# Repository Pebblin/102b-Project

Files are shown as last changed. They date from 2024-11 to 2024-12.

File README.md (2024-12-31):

# 102b-Project

## Folders
                
+ Submission
    + Project Report
    + Final Video
+ Project Code
    + Testing .ino file
    + Main code folder (contains pattern functionality)
    + Submitted code folder (meets criteria of assignment)
+ Printing Files
    + Contains different versions of printed parts used in the table
+ P4 Design
    + Contains .stl files of parts used to make the assembly CAD
+ CAD/CAD Scaled Down Model
    + Main Assembly and other .part files necessary for the assembly
    + Rudementary design of a previous project idea

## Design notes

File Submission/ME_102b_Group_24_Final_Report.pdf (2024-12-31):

# ME 102B: Kinetic Sand Table

Group 24

Rocklin Duong, Nilesh Kothari, Taylor Jazan, Rahul Kariyawasam

19th December 2024

## 1. Device Discussion

### 1.1 Opportunity

This project explores the creation of a motor-powered sand table, an engaging device that combines automation and user interaction for creating intricate patterns in sand. The opportunity lies in blending art and technology to develop a device that is functional, creative, and accessible. The sand table can serve as a captivating display piece, a creative tool, or an interactive installation, merging the worlds of technology and art in an innovative way.

### 1.2 High-Level Strategy

The sand table uses a dual-axis motorized system to move a steel ball over the sand’s surface, guided by a magnet underneath. The control system includes an ESP32 microcontroller, two motors, a motor driver, a joystick, and limit switches. This design enables two operational modes: automated and manual.
From our initial desired functionality, we were able to accomplish nearly everything that we wanted. Though we were unable to implement online functionality, we did instead allow for manual control in both cardinal and diagonal directions.

### 1.3 Design

The design of the motor-powered sand table consists of a dual-axis system using linear rails and a timing belt mechanism. The motorized system allows for precise movement of a steel ball over a sand surface to create intricate patterns. Full size photos can be found in the appendix.

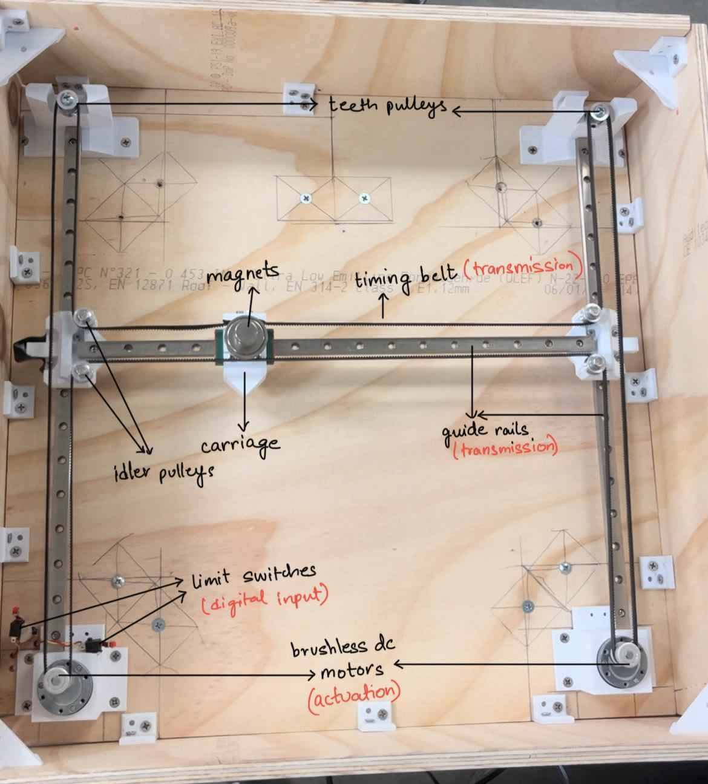
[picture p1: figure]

Figure 1: Photo of table with labels

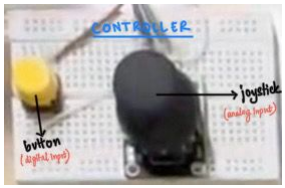
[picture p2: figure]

Figure 2: Photo of controller with labels

## 2. Calculations

In this section, we derive the key performance requirements and mechanical parameters for the linear rail and timing belt assembly used in the project. The system employs two brushed DC motors (for two degrees of freedom), a timing belt mechanism for translation, and ball bearings for load support. For simplicity and consideration of “worst case scenario,” calculations are assumed for only one motor driving the assembly.
Note that these calculations do not take into account friction between the carriage(s) and the linear rails, or the friction due to the tension of the timing belt. However, these values are assumed to be negligible due to the use of quality ball bearings in the linear rail assembly, and a relatively low belt tension, respectively.

### 2.1 Required Torque for Each Motor

The required torque for each DC motor is determined based on the motor’s maximum speed, the pulley radius, and the carriage acceleration. The system uses a pulley with radius r = 6.5 mm = 0.0065 m and a motor shaft speed of 250 rpm (revolutions per minute). The linear velocity vmax of the carriage is given by:
vmax = ω · r,

where ω is the angular velocity of the motor shaft in radians per second. Converting 250 rpm to radians per second and plugging in:

vmax = 250 ×

2π
60
- 0.0065 = 0.170 m/s.

Assuming a rapid start-stop scenario (constant acceleration), the maximum acceleration amax is estimated using kinematics:

amax =

v

2
max
2L

,

where L is the stopping distance. For simplicity, assume a realistic stopping distance L = 0.01 m. Substituting values:

amax =

(0.170)²
2 · 0.01

= 1.445 m/s²

The torque T required at the motor shaft to achieve this acceleration is given by:

T = F · r, F = m · amax

where F is the force required to accelerate the carriage. Given an assembly mass of m = 0.071 kg, the required torque is:
T = F · r = 0.071 · 1.445 · 0.0065 = 6.67 × 10⁻³ Nm (6.67 mNm).

This torque is well within the operating limits of the DC motors used, which have a maximum stall torque of 18 kg·cm, or 1.76 Nm.

### 2.2 Required Timing Belt Tension

To determine the required tension Tbelt in the timing belt, we consider the force needed to overcome inertia during acceleration and account for belt elasticity. The tension in the belt can be approximated as:

Tbelt = Fload + Fdynamic,

where Fload is the force due to carriage assembly weight, and Fdynamic is the force due to acceleration:

Fload = m · g = 0.071 · 9.81 = 0.696 N, Fdynamic = m · amax = 0.071 · 1.445 = 1.026 N.

The total belt tension required is approximately:

Tbelt = Fload + Fdynamic = 0.696 + 1.026 ≈ 1.722 N.

### 2.3 Maximum Radial Loads on Ball Bearings and Motor Shaft

The system’s ball bearings and motor shafts experience radial forces during operation due to belt tension and carriage movement. The maximum radial load on each ball bearing is approximately equal to the belt tension, as the force from the belt tension is transferred directly to the bearings.

Fbearing = Tbelt = 1.722 N.

The radial load on the motor shaft arises from the belt tension and the pulley geometry. The radial force Fshaft can be estimated using the belt tension and the belt angle of entry θ to the pulley. Assuming θ = 0◦
from our design (also a maximum load scenario):

Fshaft = Tbelt · cos(θ), Fshaft = Tbelt = 1.722 N.

The calculated loads are within the acceptable operating limits of our ball bearings and motor shafts, as the ball bearings of our system are rated for a maximum load of 200 N.

## 3. Diagrams

Full-scale photos of the below diagrams can also be found in the appendix.

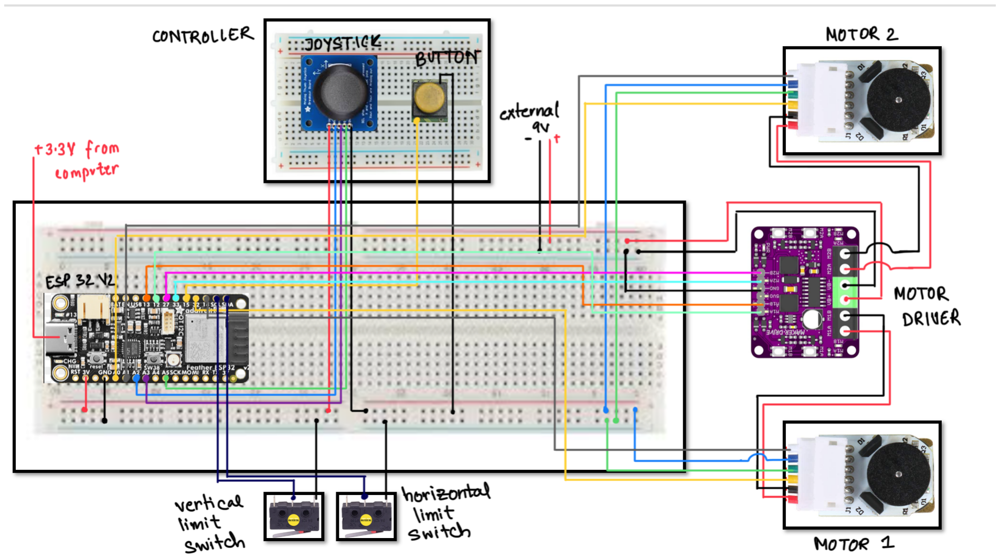
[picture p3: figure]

Figure 3: Circuit Diagram

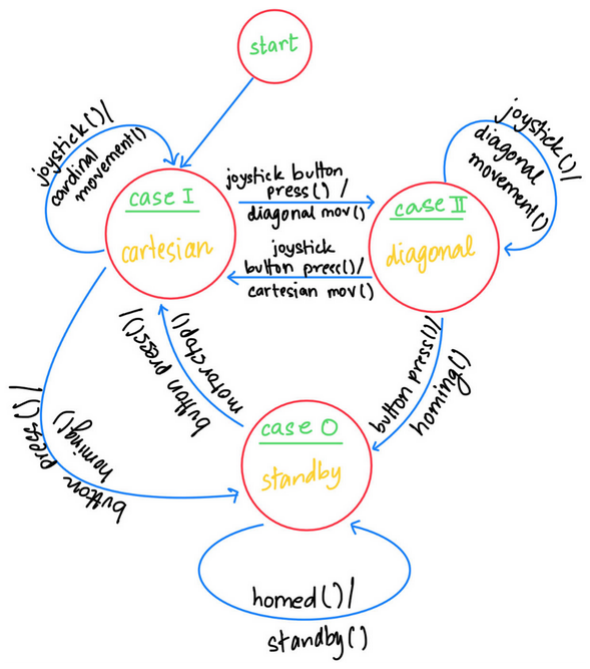
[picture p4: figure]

Figure 4: State Transition Diagram

## 4. Reflection

One strategy that worked well for our group was clear communication and task delegation. By setting realistic deadlines and holding regular check-ins, we maintained steady progress and avoided last-minute stress. However, we wish we had prototyped earlier in the process. Testing a mid-fidelity version of our design sooner would have helped us identify issues like motor strength and alignment earlier, saving time during the final build. Overall, balancing planning with hands-on testing is key to a smooth and successful project.

## 5. Appendix

### 5.1 Appendix A: Bill of Materials

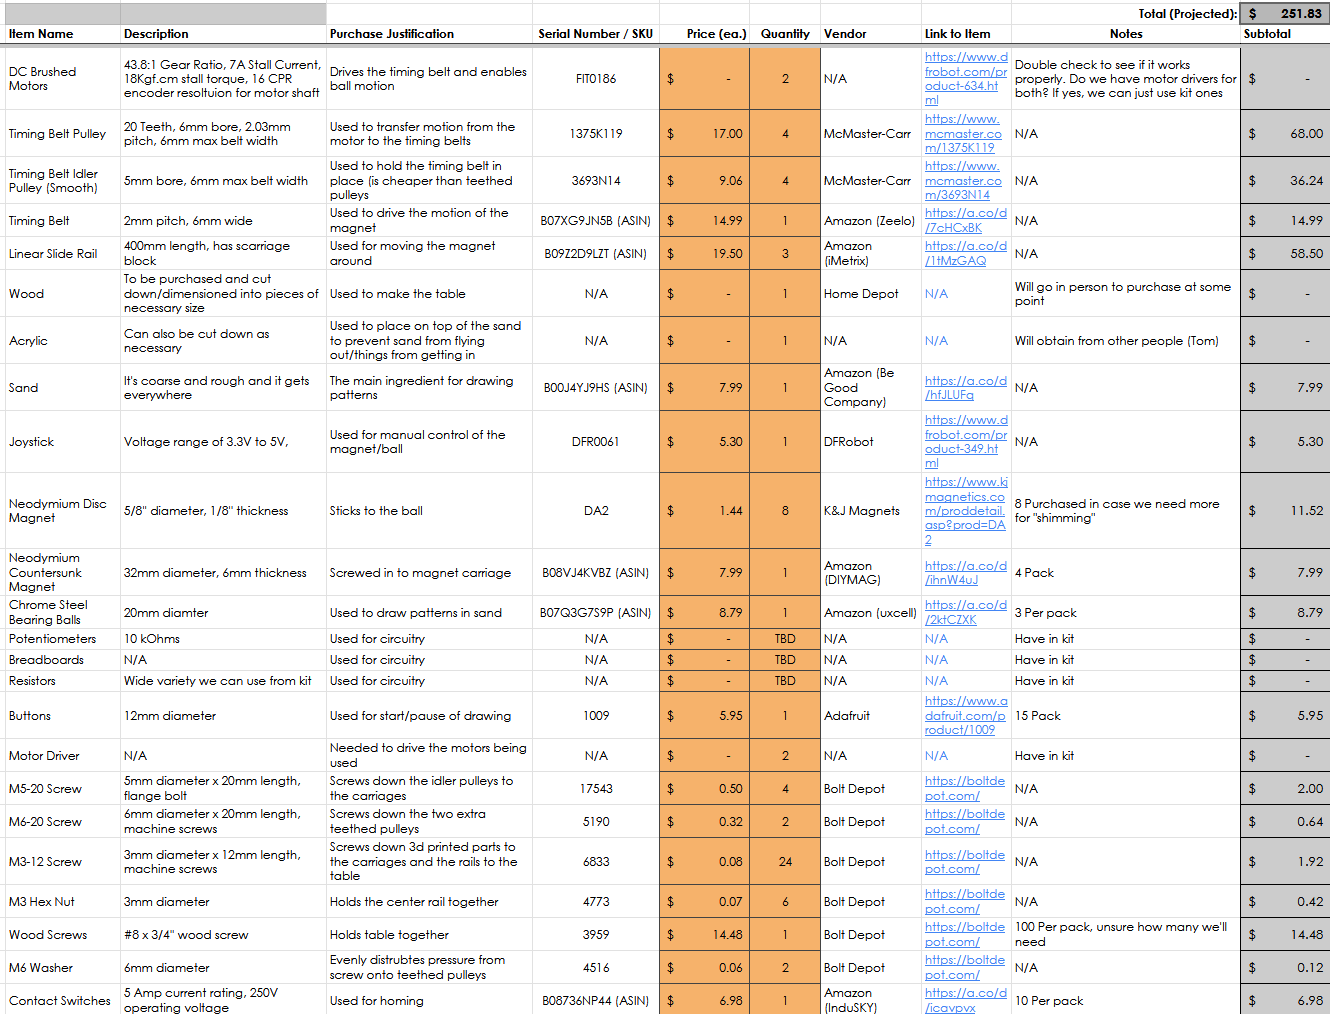
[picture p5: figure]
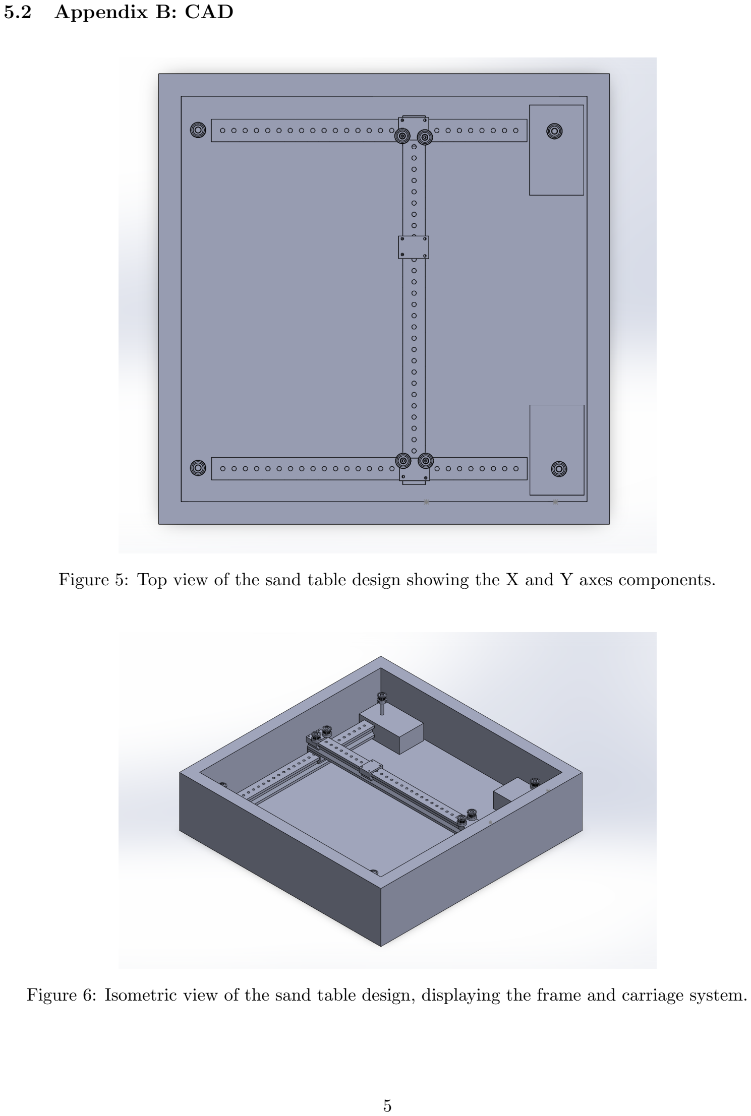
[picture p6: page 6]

### 5.2 Appendix B: CAD

Figure 5: Top view of the sand table design showing the X and Y axes components.

Figure 6: Isometric view of the sand table design, displaying the frame and carriage system.

### 5.3 Appendix C: Code Screenshots

The order of the screenshots go in order of Main.ino, then MotorControl, JoystickHandler, and EncoderHandler. For the last three classes, the .hpp file is shown then the .cpp file.

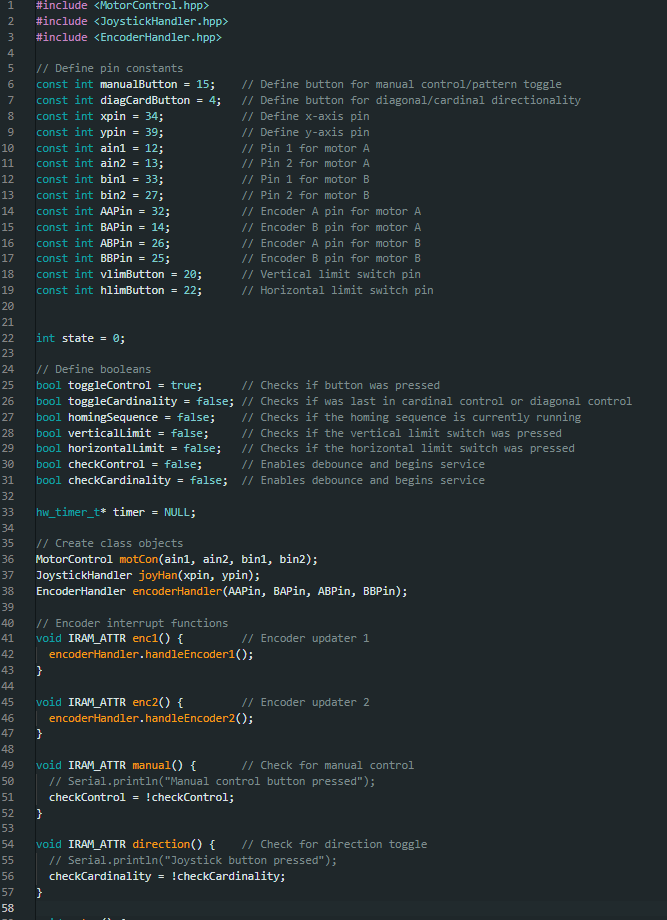
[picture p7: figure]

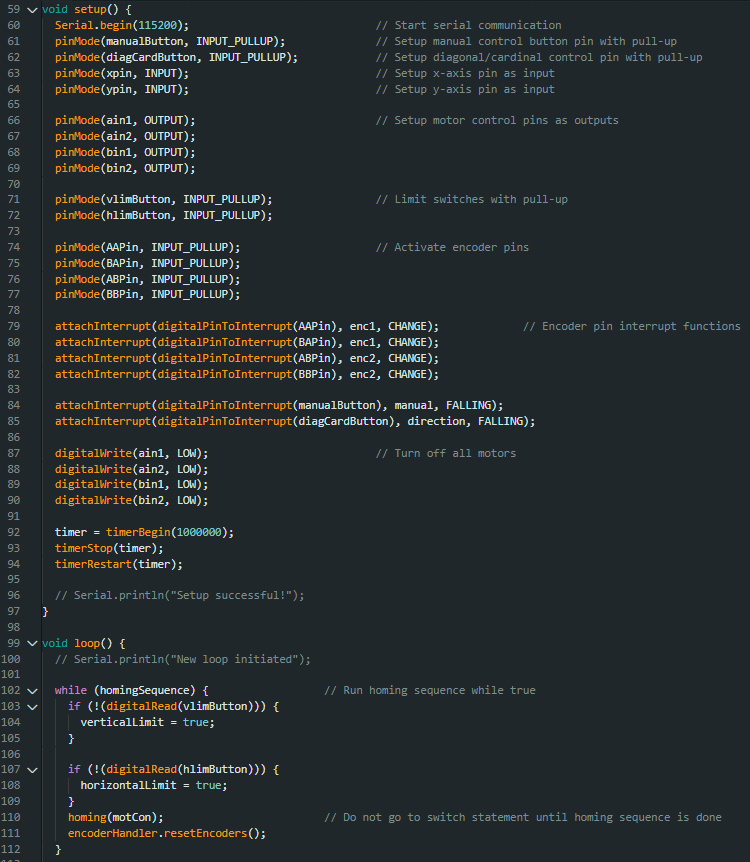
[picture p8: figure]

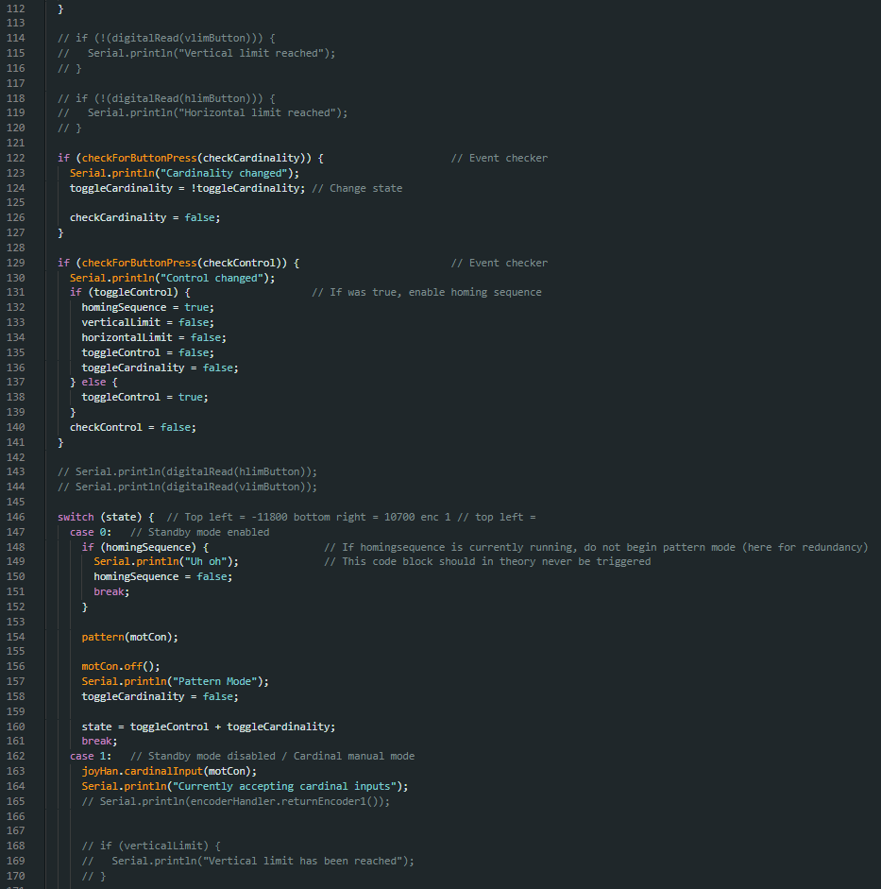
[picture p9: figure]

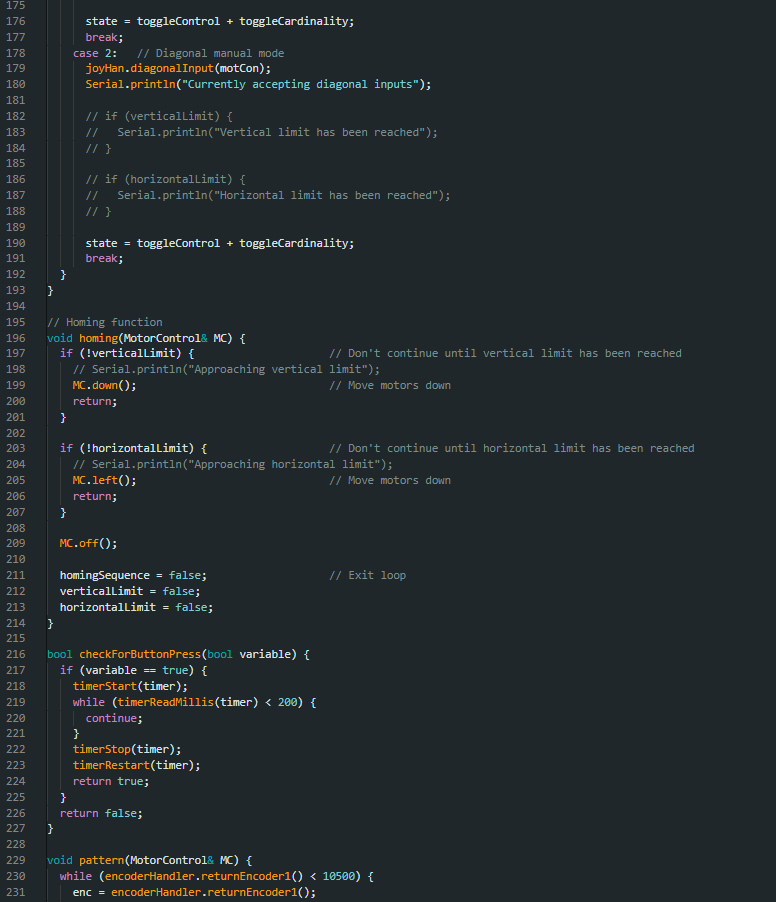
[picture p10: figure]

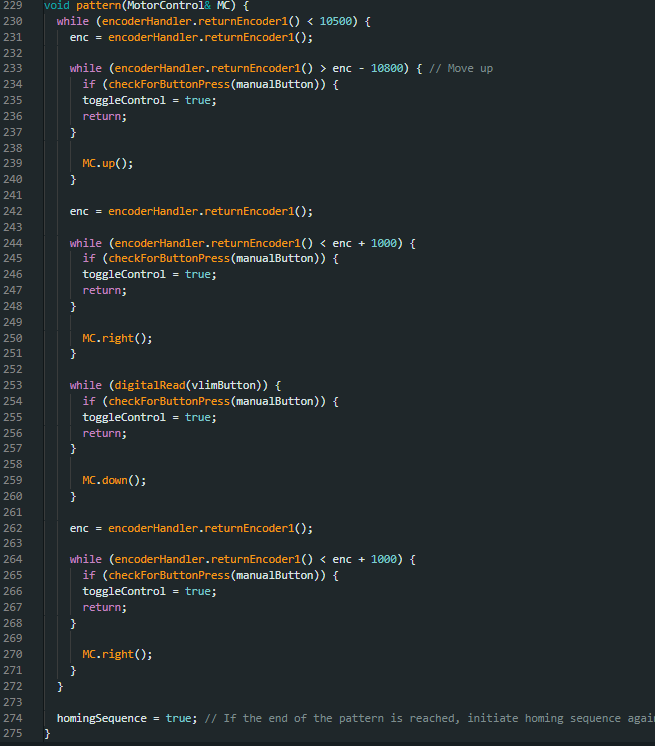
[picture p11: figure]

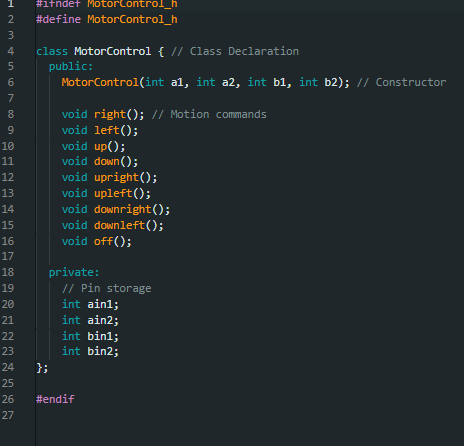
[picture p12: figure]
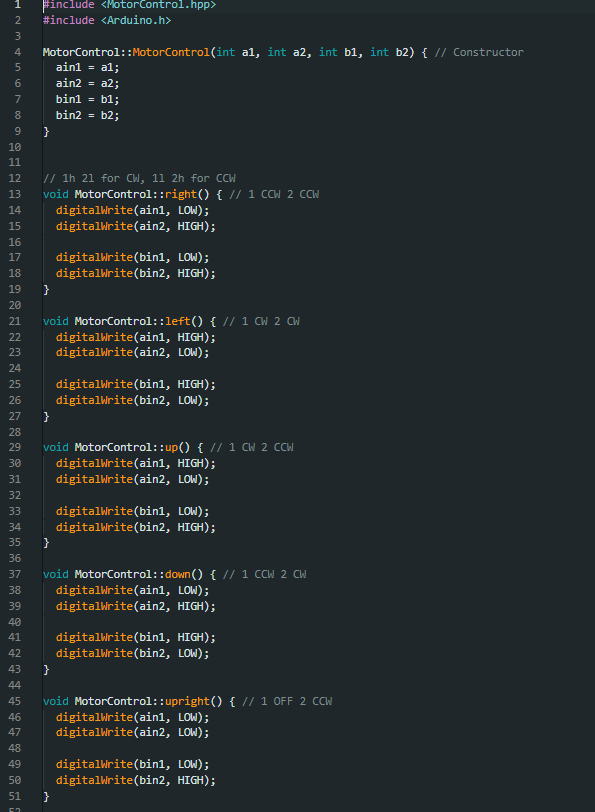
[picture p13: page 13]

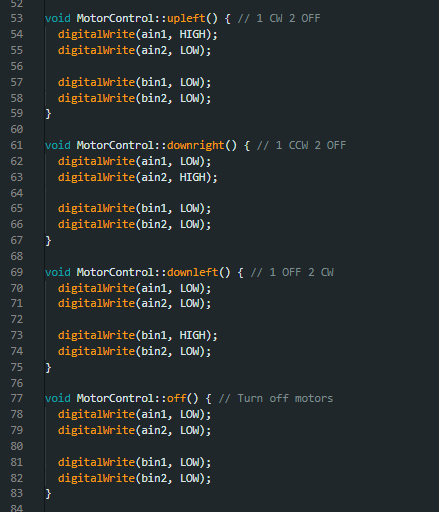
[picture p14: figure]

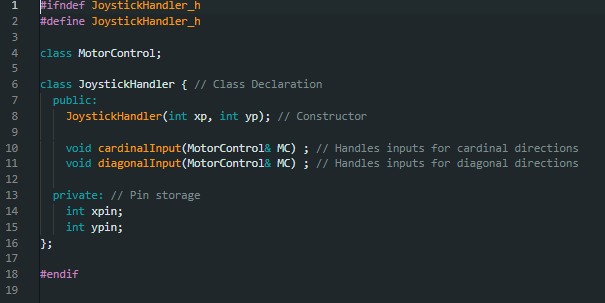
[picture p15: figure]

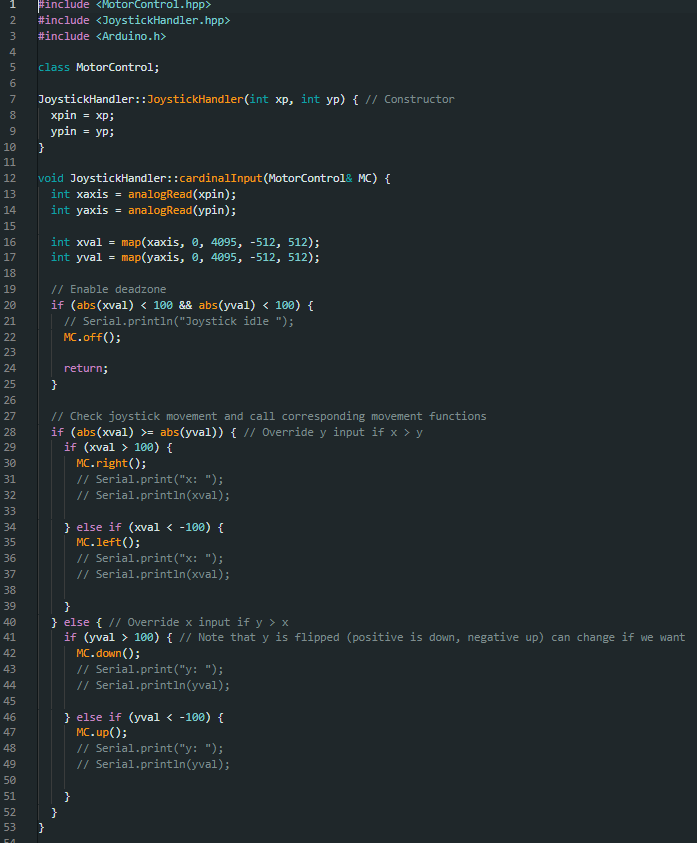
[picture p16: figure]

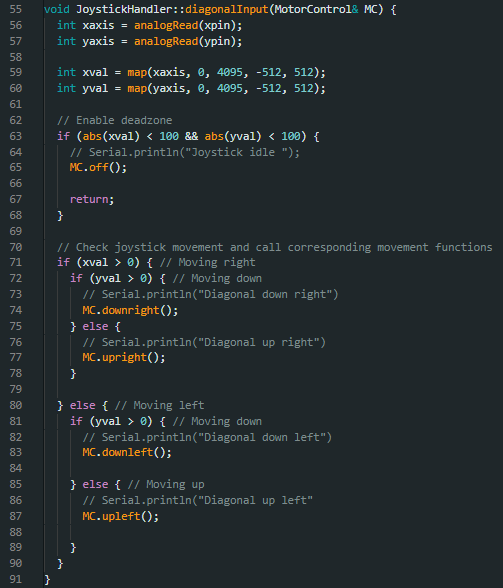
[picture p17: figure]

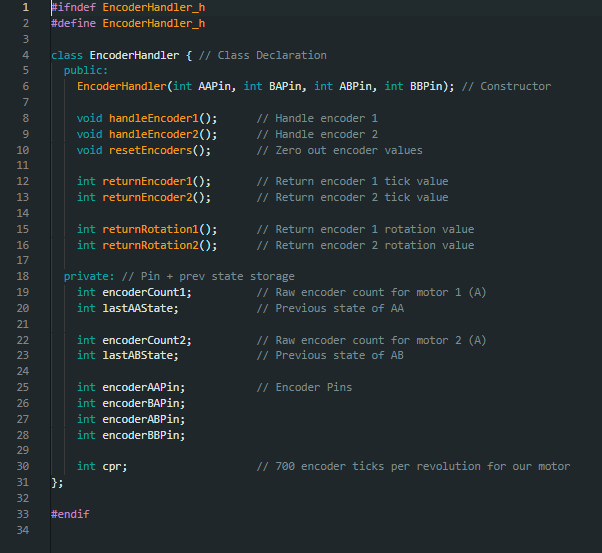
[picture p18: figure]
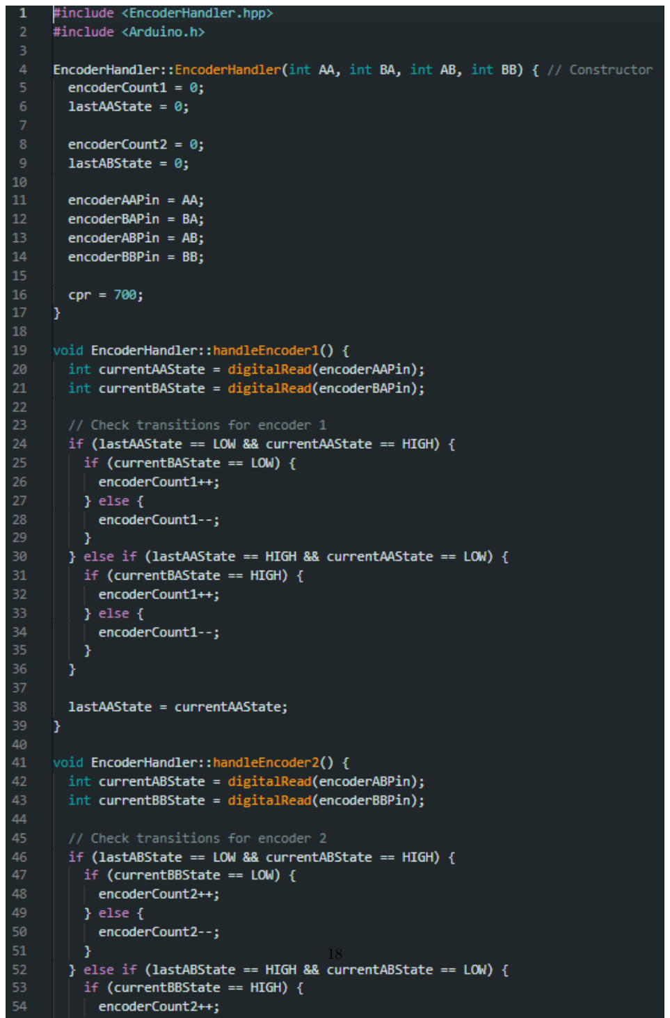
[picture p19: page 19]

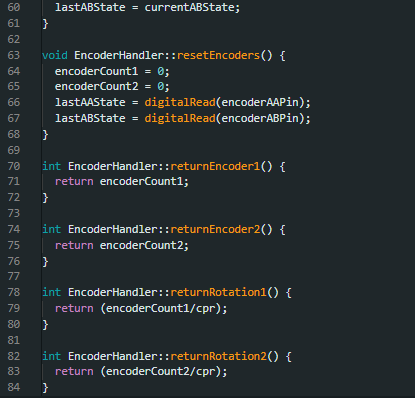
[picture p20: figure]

### 5.4 Appendix D: Additional Images/Photos

Figure 7: Full scale image of the mechanics of the sand table

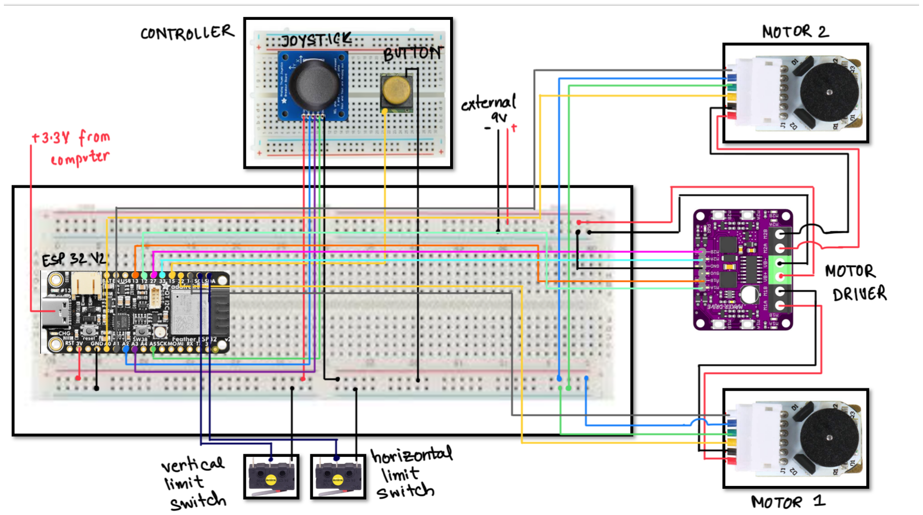
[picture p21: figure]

Figure 8: Full scale image of our circuit

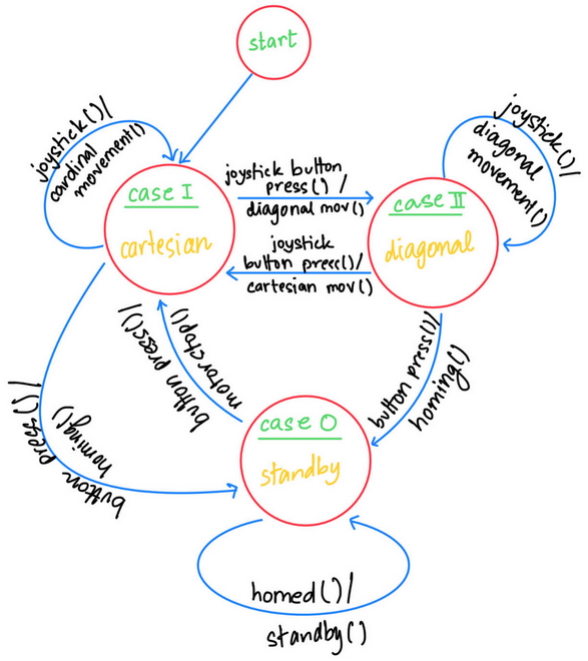
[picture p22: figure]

Figure 9: Full scale image of our state diagram

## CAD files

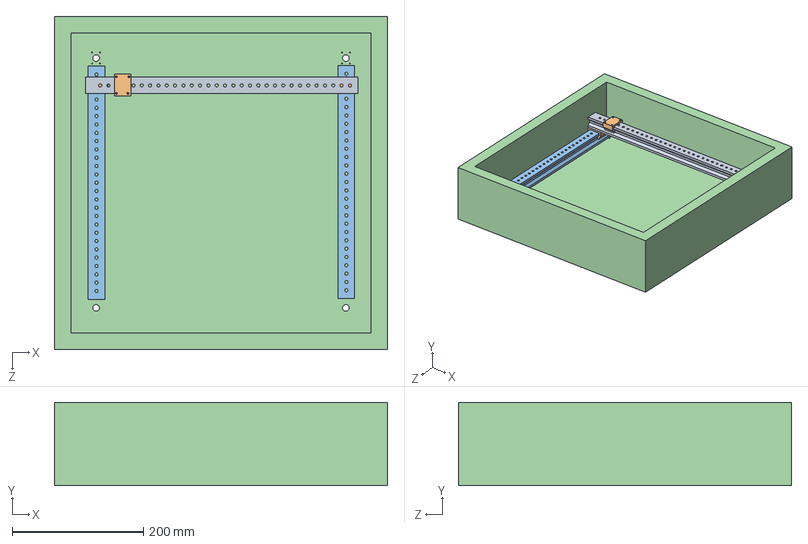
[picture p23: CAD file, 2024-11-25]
P4 Design/Main Assembly.SLDASM
508.0 x 127.0 x 508.0 mm
Base plate with stepper holes
guide rail M5 14in x 2
guide rail head 1 x 3
guide rail M5 16.37in

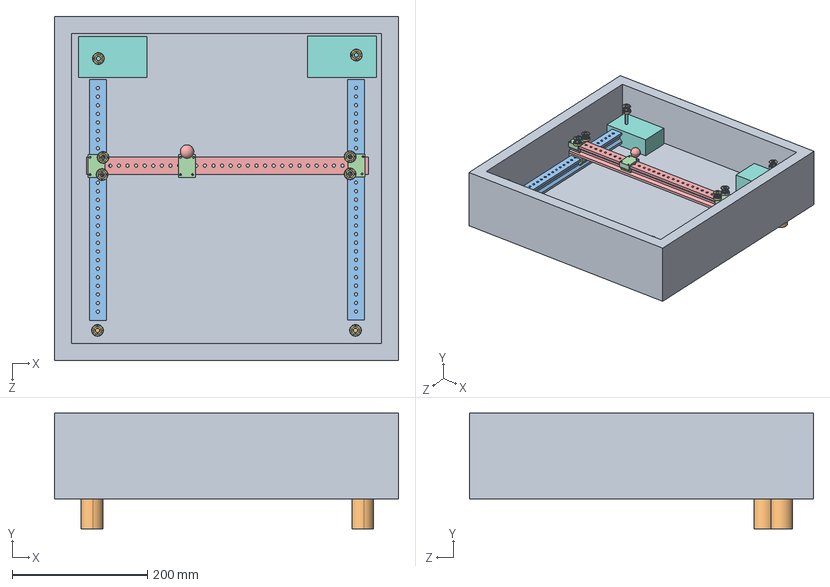
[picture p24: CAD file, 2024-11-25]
CAD/Main Assembly.STEP
508.0 x 170.6 x 508.0 mm
Base plate with stepper holes
guide rail M5 14in x 2
guide rail head 1 x 5
guide rail M5 16.37in
1375K119_MXL Series Timing Belt Pulley.step x 8
housing x 2
spur gear_ai_Inch - Spur gear 24DP 10T 20PA 0.5FW ---S10N3.0H2.0L0.25N x 4
motor x 2
spur gear_ai_Inch - Spur gear 24DP 48T 20PA 0.5FW ---S48N3.0H2.0L0.03125N x 2
spur gear_ai_Inch - Spur gear 24DP 30T 20PA 0.25FW ---S30N3.0H2.0L0.25N x 2
ball 20mm

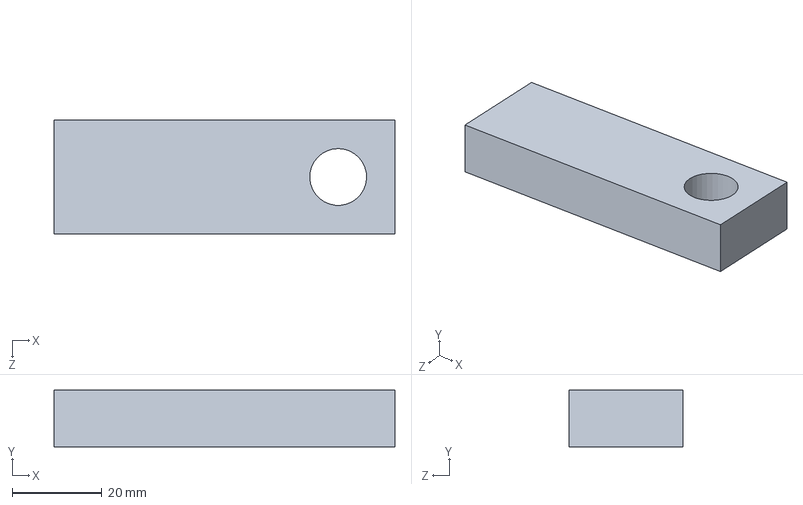
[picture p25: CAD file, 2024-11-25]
CAD Scaled Down Model/Tower.SLDPRT
76.2 x 12.7 x 25.4 mm

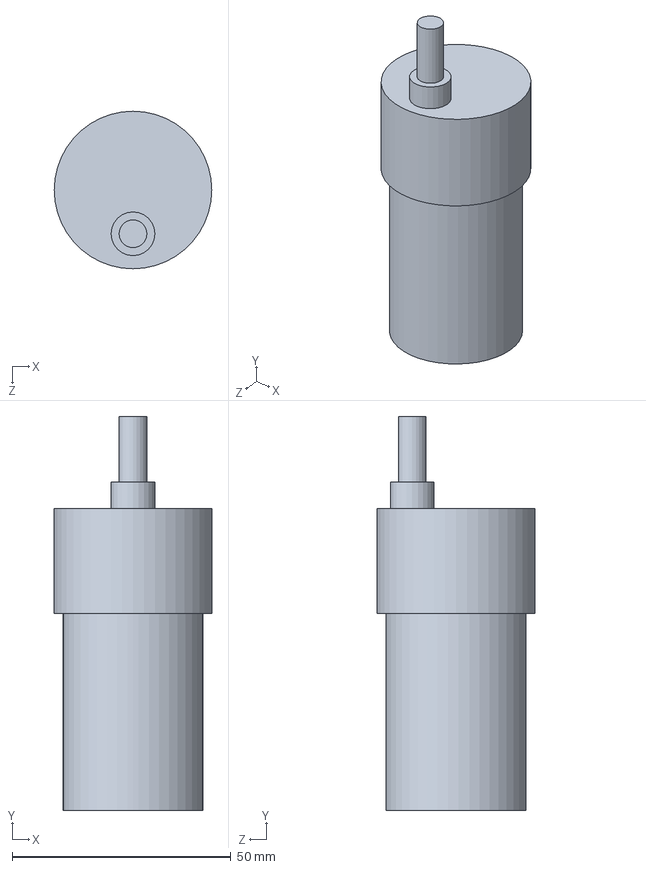
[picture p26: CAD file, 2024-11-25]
CAD/motor.SLDPRT
36.0 x 90.0 x 36.0 mm

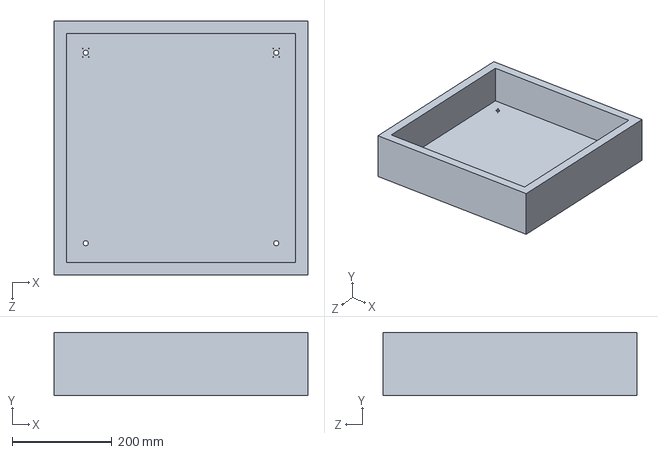
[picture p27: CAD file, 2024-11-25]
P4 Design/Base plate with stepper holes.SLDPRT
508.0 x 127.0 x 508.0 mm

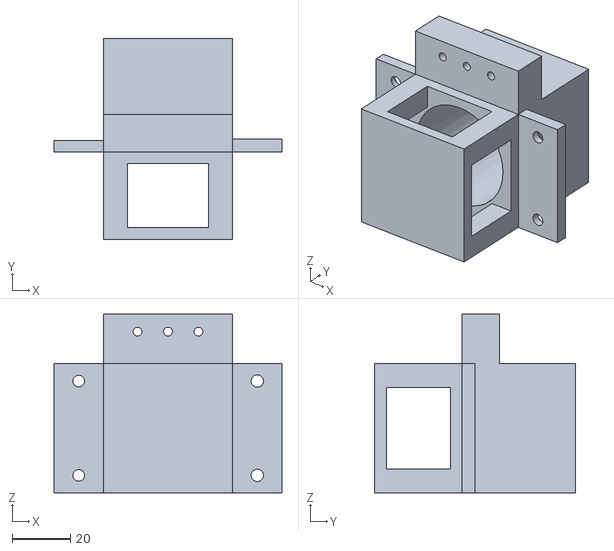
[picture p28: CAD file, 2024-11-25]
Printing Files/V3/motorhousing_v3.STL
78.5 x 69.0 x 61.5

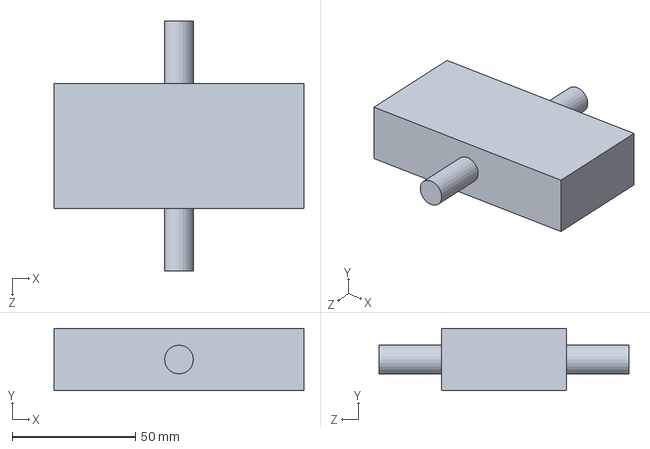
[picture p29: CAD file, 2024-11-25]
CAD Scaled Down Model/Board.SLDPRT
101.6 x 25.4 x 101.6 mm

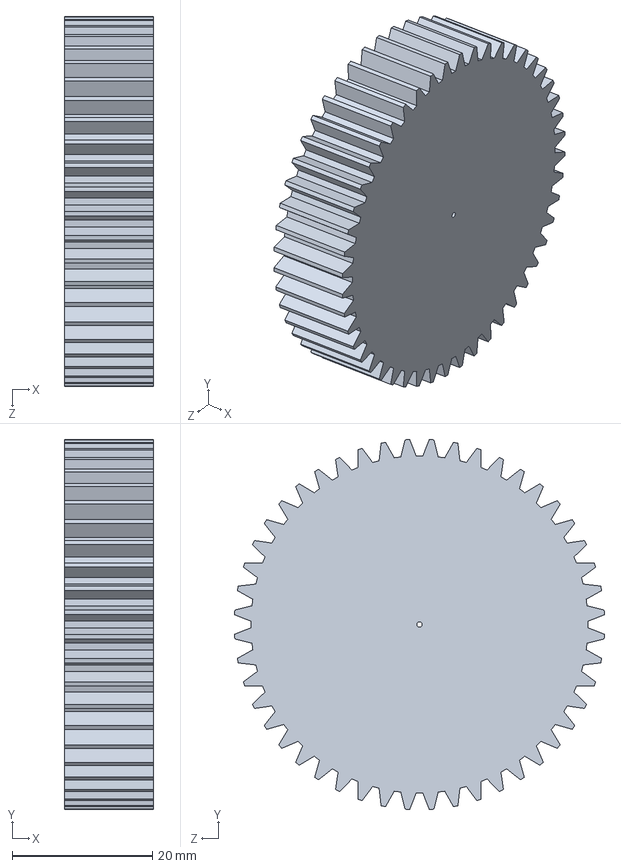
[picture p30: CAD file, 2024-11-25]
CAD/Inch - Spur gear 24DP 48T 20PA 0.5FW ---S48N3.0H2.0L0.03125N.SLDPRT
12.7 x 52.8 x 52.8 mm

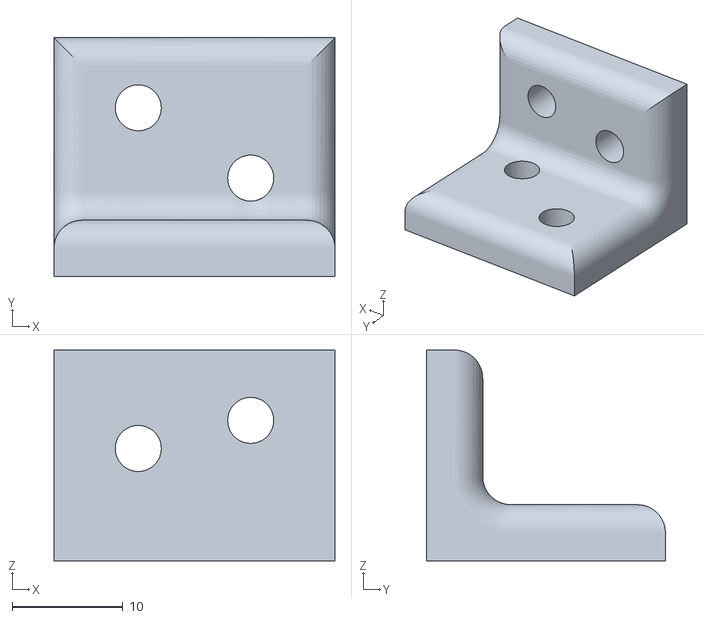
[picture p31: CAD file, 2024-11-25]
Printing Files/V3/L-clamp.STL
25.4 x 21.6 x 19.1

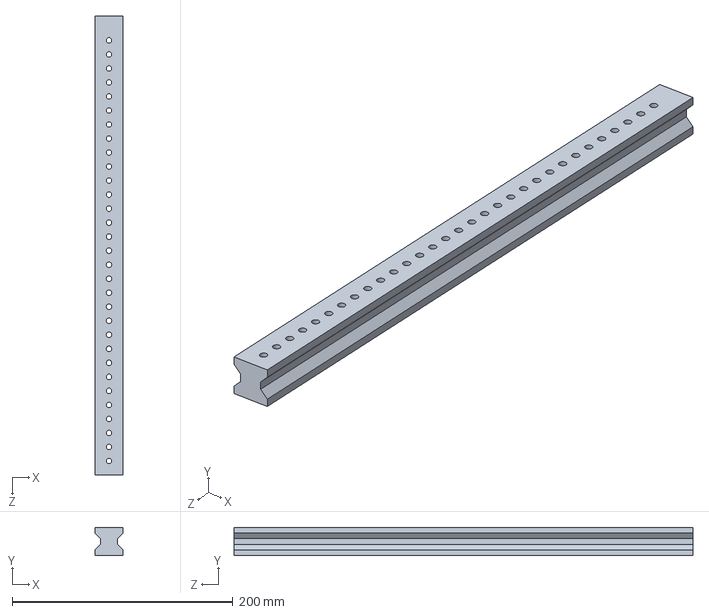
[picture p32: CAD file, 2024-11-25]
CAD/guide rail M5 16.37in.SLDPRT
25.4 x 25.4 x 415.8 mm

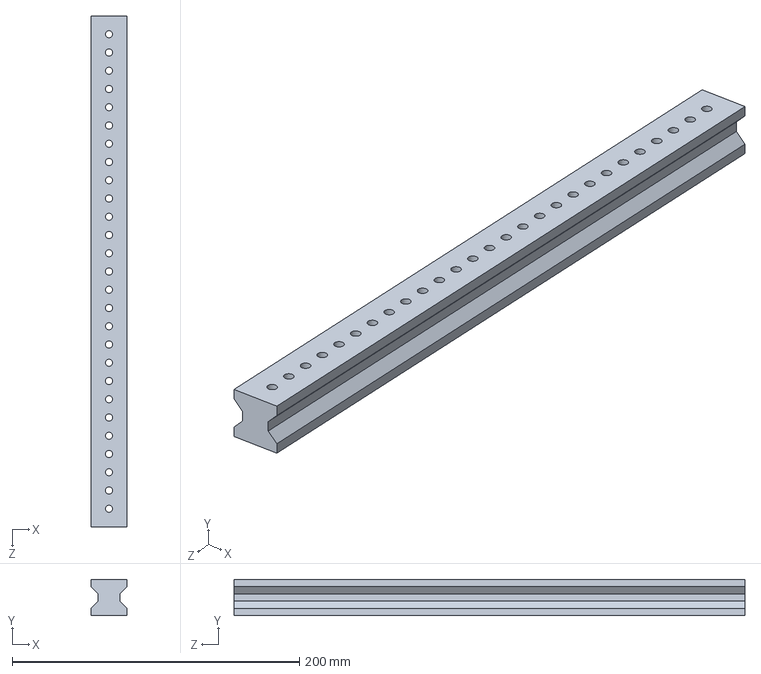
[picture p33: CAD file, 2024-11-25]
P4 Design/guide rail M5 14in.SLDPRT
25.4 x 25.4 x 355.6 mm

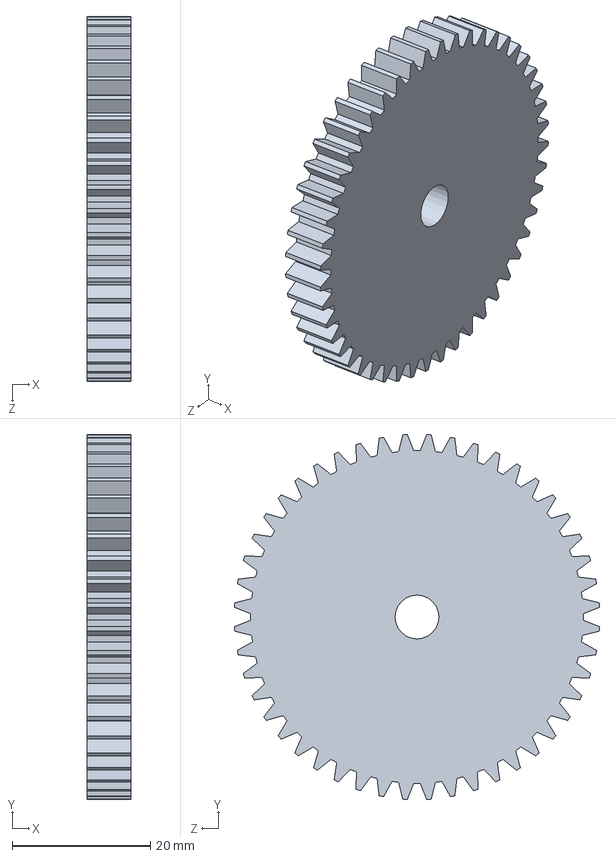
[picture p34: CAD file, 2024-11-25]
CAD/Inch - Spur gear 24DP 48T 20PA 0.5FW ---S48N3.0H2.0L0.03125N1.SLDPRT
6.35 x 52.8 x 52.8 mm

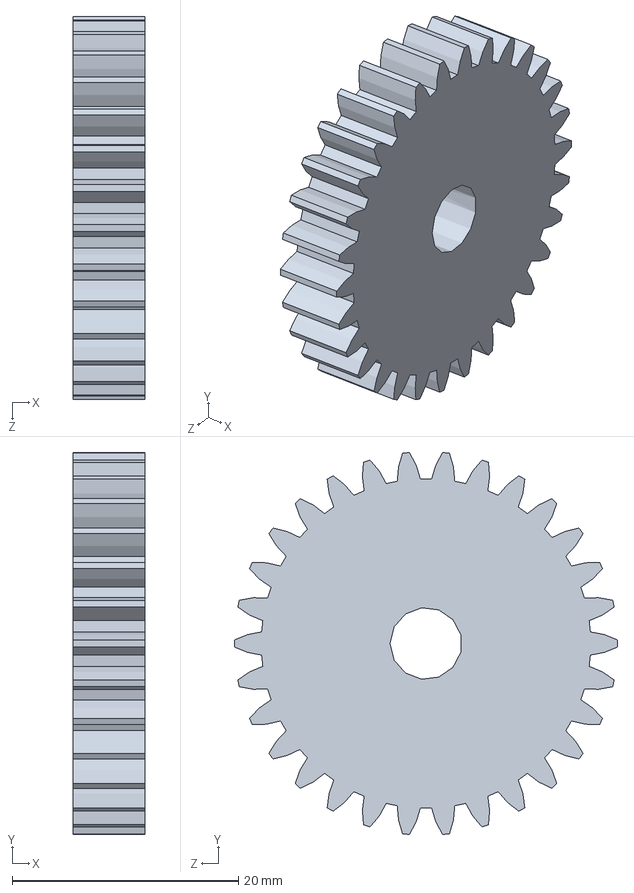
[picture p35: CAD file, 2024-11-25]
CAD/Inch - Spur gear 24DP 30T 20PA 0.25FW ---S30N3.0H2.0L0.25N.SLDPRT
6.35 x 33.7 x 33.9 mm

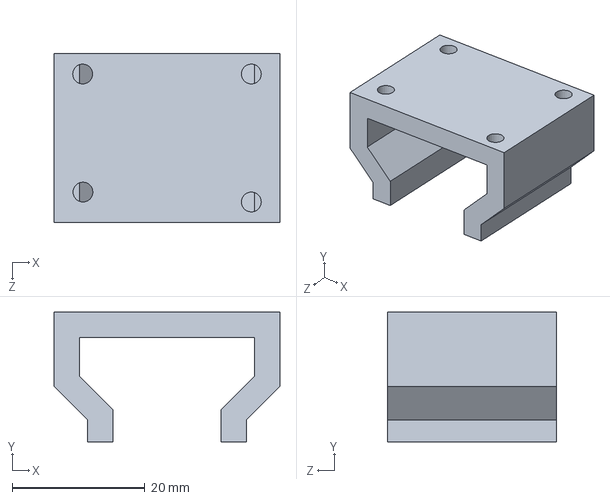
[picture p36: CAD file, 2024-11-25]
P4 Design/guide rail head 1.SLDPRT
34.0 x 19.6 x 25.4 mm

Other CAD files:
CAD/gearbox assembly.SLDASM
CAD/Base plate with stepper holes.SLDPRT
CAD Scaled Down Model/Board.STL
CAD Scaled Down Model/Tower.STL
CAD/1375K119_MXL Series Timing Belt Pulley.SLDPRT
CAD/1375K119_MXL Series Timing Belt Pulley.STEP
CAD/6627T111_Stepper Motor.SLDPRT
CAD/Inch - Spur gear 24DP 10T 20PA 0.5FW ---S10N3.0H2.0L0.25N.SLDPRT
CAD/Main Assembly.SLDASM
CAD/ball 20mm.SLDPRT
CAD/housing.SLDPRT
P4 Design/6627T111_Stepper Motor.SLDPRT
Printing Files/V1/BeltGrip.stl
Printing Files/V1/IdleSupport.stl
Printing Files/V1/MagnetMount.stl
Printing Files/V1/SW part/motorhousing_bottom.SLDPRT
Printing Files/V1/SW part/motorhousing_full.SLDPRT
Printing Files/V1/SW part/motorhousing_top.SLDPRT
Printing Files/V1/X-CarriageMount.stl
Printing Files/V1/motorhousing_bottom.STL
Printing Files/V1/motorhousing_full.STL
Printing Files/V2/BaseBoardMount.stl
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

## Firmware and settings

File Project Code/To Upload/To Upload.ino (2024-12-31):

#include <MotorControl.hpp>
#include <JoystickHandler.hpp>
#include <EncoderHandler.hpp>

// Define pin constants
const int manualButton = 15;    // Define button for manual control/pattern toggle
const int diagCardButton = 4;   // Define button for diagonal/cardinal directionality
const int xpin = 34;            // Define x-axis pin
const int ypin = 39;            // Define y-axis pin
const int ain1 = 12;            // Pin 1 for motor A
const int ain2 = 13;            // Pin 2 for motor A
const int bin1 = 33;            // Pin 1 for motor B
const int bin2 = 27;            // Pin 2 for motor B
const int AAPin = 32;           // Encoder A pin for motor A
const int BAPin = 14;           // Encoder B pin for motor A
const int ABPin = 26;           // Encoder A pin for motor B
const int BBPin = 25;           // Encoder B pin for motor B
const int vlimButton = 20;      // Vertical limit switch pin
const int hlimButton = 22;      // Horizontal limit switch pin


int state = 0;

// Define booleans
bool toggleControl = true;      // Checks if button was pressed
bool toggleCardinality = false; // Checks if was last in cardinal control or diagonal control
bool homingSequence = false;    // Checks if the homing sequence is currently running
bool verticalLimit = false;     // Checks if the vertical limit switch was pressed
bool horizontalLimit = false;   // Checks if the horizontal limit switch was pressed
bool checkControl = false;      // Enables debounce and begins service
bool checkCardinality = false;  // Enables debounce and begins service

hw_timer_t* timer = NULL;

// Create class objects
MotorControl motCon(ain1, ain2, bin1, bin2);
JoystickHandler joyHan(xpin, ypin);
EncoderHandler encoderHandler(AAPin, BAPin, ABPin, BBPin);

// Encoder interrupt functions
void IRAM_ATTR enc1() {         // Encoder updater 1
  encoderHandler.handleEncoder1();
}

void IRAM_ATTR enc2() {         // Encoder updater 2
  encoderHandler.handleEncoder2();
}

void IRAM_ATTR manual() {       // Check for manual control
  // Serial.println("Manual control button pressed");
  checkControl = !checkControl;
}

void IRAM_ATTR direction() {    // Check for direction toggle 
  // Serial.println("Joystick button pressed");
  checkCardinality = !checkCardinality;
}

void setup() {
  Serial.begin(115200);                             // Start serial communication
  pinMode(manualButton, INPUT_PULLUP);              // Setup manual control button pin with pull-up
  pinMode(diagCardButton, INPUT_PULLUP);            // Setup diagonal/cardinal control pin with pull-up
  pinMode(xpin, INPUT);                             // Setup x-axis pin as input
  pinMode(ypin, INPUT);                             // Setup y-axis pin as input

  pinMode(ain1, OUTPUT);                            // Setup motor control pins as outputs
  pinMode(ain2, OUTPUT);
  pinMode(bin1, OUTPUT);
  pinMode(bin2, OUTPUT);

  pinMode(vlimButton, INPUT_PULLUP);                // Limit switches with pull-up
  pinMode(hlimButton, INPUT_PULLUP);

  pinMode(AAPin, INPUT_PULLUP);                     // Activate encoder pins
  pinMode(BAPin, INPUT_PULLUP);
  pinMode(ABPin, INPUT_PULLUP);
  pinMode(BBPin, INPUT_PULLUP);

  attachInterrupt(digitalPinToInterrupt(AAPin), enc1, CHANGE);             // Encoder pin interrupt functions
  attachInterrupt(digitalPinToInterrupt(BAPin), enc1, CHANGE);
  attachInterrupt(digitalPinToInterrupt(ABPin), enc2, CHANGE);
  attachInterrupt(digitalPinToInterrupt(BBPin), enc2, CHANGE);

  attachInterrupt(digitalPinToInterrupt(manualButton), manual, FALLING);
  attachInterrupt(digitalPinToInterrupt(diagCardButton), direction, FALLING);

  digitalWrite(ain1, LOW);                          // Turn off all motors
  digitalWrite(ain2, LOW);
  digitalWrite(bin1, LOW);
  digitalWrite(bin2, LOW);

  timer = timerBegin(1000000);
  timerStop(timer);
  timerRestart(timer); 

  // Serial.println("Setup successful!");
}

void loop() {
  // Serial.println("New loop initiated");

  while (homingSequence) {                  // Run homing sequence while true
    if (!(digitalRead(vlimButton))) {
      verticalLimit = true;
    }

    if (!(digitalRead(hlimButton))) {
      horizontalLimit = true;
    }
    homing(motCon);                         // Do not go to switch statement until homing sequence is done
    encoderHandler.resetEncoders();
  }

  // if (!(digitalRead(vlimButton))) {
  //   Serial.println("Vertical limit reached");
  // }

  // if (!(digitalRead(hlimButton))) {
  //   Serial.println("Horizontal limit reached");
  // }

  if (checkForButtonPress(checkCardinality)) {                     // Event checker
    Serial.println("Cardinality changed");
    toggleCardinality = !toggleCardinality; // Change state

    checkCardinality = false;
  }

  if (checkForButtonPress(checkControl)) {                         // Event checker
    Serial.println("Control changed");
    if (toggleControl) {                    // If was true, enable homing sequence
      homingSequence = true;
      verticalLimit = false;
      horizontalLimit = false;
      toggleControl = false;
      toggleCardinality = false;
    } else {
      toggleControl = true;
    }
    checkControl = false;
  }

  // Serial.println(digitalRead(hlimButton));
  // Serial.println(digitalRead(vlimButton));

  switch (state) {  // Top left = -11800 bottom right = 10700 enc 1 // top left =
    case 0:   // Standby mode enabled
      if (homingSequence) {                   // If homingsequence is currently running, do not begin pattern mode (here for redundancy)
        Serial.println("Uh oh");              // This code block should in theory never be triggered
        homingSequence = false;
        break;
      } 

      // pattern(motCon);

      motCon.off();
      Serial.println("Standby Mode");
      toggleCardinality = false;

      state = toggleControl + toggleCardinality;
      break;
    case 1:   // Standby mode disabled / Cardinal manual mode
      joyHan.cardinalInput(motCon);
      Serial.println("Currently accepting cardinal inputs");
      // Serial.println(encoderHandler.returnEncoder1());


      // if (verticalLimit) {
      //   Serial.println("Vertical limit has been reached");
      // }

      // if (horizontalLimit) {
      //   Serial.println("Horizontal limit has been reached");
      // }

      state = toggleControl + toggleCardinality;
      break;
    case 2:   // Diagonal manual mode
      joyHan.diagonalInput(motCon);
      Serial.println("Currently accepting diagonal inputs");

      // if (verticalLimit) {
      //   Serial.println("Vertical limit has been reached");
      // }

      // if (horizontalLimit) {
      //   Serial.println("Horizontal limit has been reached");
      // }

      state = toggleControl + toggleCardinality;
      break;
  }
}

// Homing function
void homing(MotorControl& MC) {
  if (!verticalLimit) {                     // Don't continue until vertical limit has been reached
    // Serial.println("Approaching vertical limit");
    MC.down();                              // Move motors down
    return;
  }

  if (!horizontalLimit) {                   // Don't continue until horizontal limit has been reached
    // Serial.println("Approaching horizontal limit");
    MC.left();                              // Move motors down
    return;
  }

  MC.off();

  homingSequence = false;                   // Exit loop
  verticalLimit = false;
  horizontalLimit = false;
}

bool checkForButtonPress(bool variable) {
  if (variable == true) {
    timerStart(timer);
    while (timerReadMillis(timer) < 200) {
      continue;
    }
    timerStop(timer);
    timerRestart(timer);
    return true;
  }
  return false;
}

void pattern(MotorControl& MC) { // To be implemented
  while (encoderHandler.returnEncoder1() > -11000) {
    if (checkForButtonPress(manualButton)) {
      toggleControl = true;
      return;
    }
    MC.up();
  }

  while (encoderHandler.returnEncoder1() < -10500) {
    if (checkForButtonPress(manualButton)) {
      toggleControl = true;
      return;
    }
    MC.right();
  }

  while (encoderHandler.returnEncoder1() < 500) {
    if (checkForButtonPress(manualButton)) {
      toggleControl = true;
      return;
    }
    MC.down();
  }

  while (encoderHandler.returnEncoder1() < 1000) {
    if (checkForButtonPress(manualButton)) {
      toggleControl = true;
      return;
    }
    MC.right();
  }

  while (encoderHandler.returnEncoder1() > -10000) {
    if (checkForButtonPress(manualButton)) {
      toggleControl = true;
      return;
    }
    MC.up();
  }

  while (encoderHandler.returnEncoder1() < -9500) {
    if (checkForButtonPress(manualButton)) {
      toggleControl = true;
      return;
    }
    MC.right();
  }

  while (encoderHandler.returnEncoder1() < 1500) {
    if (checkForButtonPress(manualButton)) {
      toggleControl = true;
      return;
    }
    MC.down();
  }

  while (encoderHandler.returnEncoder1() < 2000) {
    if (checkForButtonPress(manualButton)) {
      toggleControl = true;
      return;
    }
    MC.right();
  }

  while (encoderHandler.returnEncoder1() > -9000) {
    if (checkForButtonPress(manualButton)) {
      toggleControl = true;
      return;
    }
    MC.up();
  }

  while (encoderHandler.returnEncoder1() < -8500) {
    if (checkForButtonPress(manualButton)) {
      toggleControl = true;
      return;
    }
    MC.right();
  }

  while (encoderHandler.returnEncoder1() < 2500) {
    if (checkForButtonPress(manualButton)) {
      toggleControl = true;
      return;
    }
    MC.down();
  }

  while (encoderHandler.returnEncoder1() < 3000) {
    if (checkForButtonPress(manualButton)) {
      toggleControl = true;
      return;
    }
    MC.right();
  }

  while (encoderHandler.returnEncoder1() > -8000) {
    if (checkForButtonPress(manualButton)) {
      toggleControl = true;
      return;
    }
    MC.up();
  }

  while (encoderHandler.returnEncoder1() < -7500) {
    if (checkForButtonPress(manualButton)) {
      toggleControl = true;
      return;
    }
    MC.right();
  }

  while (encoderHandler.returnEncoder1() < 3500) {
    if (checkForButtonPress(manualButton)) {
      toggleControl = true;
      return;
    }
    MC.down();
  }

  while (encoderHandler.returnEncoder1() < 4000) {
    if (checkForButtonPress(manualButton)) {
      toggleControl = true;
      return;
    }
    MC.right();
  }

  while (encoderHandler.returnEncoder1() > -7000) {
    if (checkForButtonPress(manualButton)) {
      toggleControl = true;
      return;
    }
    MC.up();
  }

  while (encoderHandler.returnEncoder1() < -6500) {
    if (checkForButtonPress(manualButton)) {
      toggleControl = true;
      return;
    }
    MC.right();
  }

  while (encoderHandler.returnEncoder1() < 4500) {
    if (checkForButtonPress(manualButton)) {
      toggleControl = true;
      return;
    }
    MC.down();
  }

  while (encoderHandler.returnEncoder1() < 5000) {
    if (checkForButtonPress(manualButton)) {
      toggleControl = true;
      return;
    }
    MC.right();
  }

  while (encoderHandler.returnEncoder1() > -6000) {
    if (checkForButtonPress(manualButton)) {
      toggleControl = true;
      return;
    }
    MC.up();
  }

  while (encoderHandler.returnEncoder1() < -5500) {
    if (checkForButtonPress(manualButton)) {
      toggleControl = true;
      return;
    }
    MC.right();
  }

  while (encoderHandler.returnEncoder1() < 5500) {
    if (checkForButtonPress(manualButton)) {
      toggleControl = true;
      return;
    }
    MC.down();
  }

  while (encoderHandler.returnEncoder1() < 6000) {
    if (checkForButtonPress(manualButton)) {
      toggleControl = true;
      return;
    }
    MC.right();
  }

  while (encoderHandler.returnEncoder1() > -5000) {
    if (checkForButtonPress(manualButton)) {
      toggleControl = true;
      return;
    }
    MC.up();
  }

  while (encoderHandler.returnEncoder1() < -4500) {
    if (checkForButtonPress(manualButton)) {
      toggleControl = true;
      return;
    }
    MC.right();
  }

  while (encoderHandler.returnEncoder1() < 6500) {
    if (checkForButtonPress(manualButton)) {
      toggleControl = true;
      return;
    }
    MC.down();
  }

  while (encoderHandler.returnEncoder1() < 7000) {
    if (checkForButtonPress(manualButton)) {
      toggleControl = true;
      return;
    }
    MC.right();
  }

  while (encoderHandler.returnEncoder1() > -4000) {
    if (checkForButtonPress(manualButton)) {
      toggleControl = true;
      return;
    }
    MC.up();
  }

  while (encoderHandler.returnEncoder1() < -3500) {
    if (checkForButtonPress(manualButton)) {
      toggleControl = true;
      return;
    }
    MC.right();
  }

  while (encoderHandler.returnEncoder1() < 7500) {
    if (checkForButtonPress(manualButton)) {
      toggleControl = true;
      return;
    }
    MC.down();
  }

  while (encoderHandler.returnEncoder1() < 8000) {
    if (checkForButtonPress(manualButton)) {
      toggleControl = true;
      return;
    }
    MC.right();
  }

  while (encoderHandler.returnEncoder1() > -4000) {
    if (checkForButtonPress(manualButton)) {
      toggleControl = true;
      return;
    }
    MC.up();
  }

  while (encoderHandler.returnEncoder1() < -3500) {
    if (checkForButtonPress(manualButton)) {
      toggleControl = true;
      return;
    }
    MC.right();
  }

  while (encoderHandler.returnEncoder1() < 8500) {
    if (checkForButtonPress(manualButton)) {
      toggleControl = true;
      return;
    }
    MC.down();
  }

  while (encoderHandler.returnEncoder1() < 9000) {
    if (checkForButtonPress(manualButton)) {
      toggleControl = true;
      return;
    }
    MC.right();
  }

  while (encoderHandler.returnEncoder1() > -3000) {
    if (checkForButtonPress(manualButton)) {
      toggleControl = true;
      return;
    }
    MC.up();
  }

  while (encoderHandler.returnEncoder1() < -2500) {
    if (checkForButtonPress(manualButton)) {
      toggleControl = true;
      return;
    }
    MC.right();
  }

  while (encoderHandler.returnEncoder1() < 9500) {
    if (checkForButtonPress(manualButton)) {
      toggleControl = true;
      return;
    }
    MC.down();
  }
  homingSequence = true; // If the of the pattern is reached, initiate homing sequence again
}

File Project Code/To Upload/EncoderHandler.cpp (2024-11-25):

#include <EncoderHandler.hpp>
#include <Arduino.h>

EncoderHandler::EncoderHandler(int AA, int BA, int AB, int BB) { // Constructor
  encoderCount1 = 0;
  lastAAState = 0;

  encoderCount2 = 0;
  lastABState = 0;

  encoderAAPin = AA;
  encoderBAPin = BA;
  encoderABPin = AB;
  encoderBBPin = BB;

  cpr = 700;
}

void EncoderHandler::handleEncoder1() {
  int currentAAState = digitalRead(encoderAAPin);
  int currentBAState = digitalRead(encoderBAPin);

  // Check transitions for encoder 1
  if (lastAAState == LOW && currentAAState == HIGH) {
    if (currentBAState == LOW) {
      encoderCount1++;
    } else {
      encoderCount1--;
    }
  } else if (lastAAState == HIGH && currentAAState == LOW) {
    if (currentBAState == HIGH) {
      encoderCount1++;
    } else {
      encoderCount1--;
    }
  }

  lastAAState = currentAAState;
}

void EncoderHandler::handleEncoder2() {
  int currentABState = digitalRead(encoderABPin);
  int currentBBState = digitalRead(encoderBBPin);

  // Check transitions for encoder 2
  if (lastABState == LOW && currentABState == HIGH) {
    if (currentBBState == LOW) {
      encoderCount2++;
    } else {
      encoderCount2--;
    }
  } else if (lastABState == HIGH && currentABState == LOW) {
    if (currentBBState == HIGH) {
      encoderCount2++;
    } else {
      encoderCount2--;
    }
  }

  lastABState = currentABState;
}

void EncoderHandler::resetEncoders() {
  encoderCount1 = 0;
  encoderCount2 = 0;
  lastAAState = digitalRead(encoderAAPin);
  lastABState = digitalRead(encoderABPin);
}

int EncoderHandler::returnEncoder1() {
  return encoderCount1;
}

int EncoderHandler::returnEncoder2() {
  return encoderCount2;
}

int EncoderHandler::returnRotation1() {
  return (encoderCount1/cpr);
}

int EncoderHandler::returnRotation2() {
  return (encoderCount2/cpr);
}

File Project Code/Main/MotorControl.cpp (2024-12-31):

#include <MotorControl.hpp>
#include <Arduino.h>

MotorControl::MotorControl(int a1, int a2, int b1, int b2) { // Constructor
  ain1 = a1;
  ain2 = a2;
  bin1 = b1;
  bin2 = b2;
}


// 1h 2l for CW, 1l 2h for CCW
void MotorControl::right() { // 1 CCW 2 CCW
  digitalWrite(ain1, LOW);
  digitalWrite(ain2, HIGH);

  digitalWrite(bin1, LOW);
  digitalWrite(bin2, HIGH);
}

void MotorControl::left() { // 1 CW 2 CW
  digitalWrite(ain1, HIGH);
  digitalWrite(ain2, LOW);

  digitalWrite(bin1, HIGH);
  digitalWrite(bin2, LOW);
}

void MotorControl::up() { // 1 CCW 2 CW
  digitalWrite(ain1, LOW);
  digitalWrite(ain2, HIGH);

  digitalWrite(bin1, HIGH);
  digitalWrite(bin2, LOW);
}

void MotorControl::down() { // 1 CCW 2 CW
  digitalWrite(ain1, LOW);
  digitalWrite(ain2, HIGH);

  digitalWrite(bin1, LOW);
  digitalWrite(bin2, HIGH);
}

void MotorControl::upright() { // 1 OFF 2 CCW
  digitalWrite(ain1, LOW);
  digitalWrite(ain2, LOW);

  digitalWrite(bin1, LOW);
  digitalWrite(bin2, HIGH);
}

void MotorControl::upleft() { // 1 CCW 2 OFF
  digitalWrite(ain1, LOW);
  digitalWrite(ain2, HIGH);

  digitalWrite(bin1, LOW);
  digitalWrite(bin2, LOW);
}

void MotorControl::downright() { // 1 CW 2 OFF
  digitalWrite(ain1, HIGH);
  digitalWrite(ain2, LOW);

  digitalWrite(bin1, LOW);
  digitalWrite(bin2, LOW);
}

void MotorControl::downleft() { // 1 OFF 2 CW
  digitalWrite(ain1, LOW);
  digitalWrite(ain2, LOW);

  digitalWrite(bin1, HIGH);
  digitalWrite(bin2, LOW);
}

void MotorControl::off() { // Turn off motors
  digitalWrite(ain1, LOW);
  digitalWrite(ain2, LOW);

  digitalWrite(bin1, LOW);
  digitalWrite(bin2, LOW);
}

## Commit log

2024-11-25 throwing everything in lol
    [1375K119_MXL Series Timing Belt Pulley.SLDPRT, 1375K119_MXL Series Timing Belt Pulley.STEP, 6627T111_Stepper Motor.SLDPRT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]
2024-11-25 Finished implementing encoder updates
2024-12-31 gitignore update
    [Main Assembly.STEP]
